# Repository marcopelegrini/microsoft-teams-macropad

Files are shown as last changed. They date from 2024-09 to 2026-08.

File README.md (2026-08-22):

# Microsoft Teams Macropad

Microsoft Teams Macropad is a physical device, programmed specifically for Microsoft Teams with dedicated keys for triggering functionalities such as "mute" or "raise hand", as well as reactions to meetings and chats!

Documentation: https://pelegrini.ca/hardware/2024/11/10/marcopad/

These are all the asseets I've used to create the macropad. 

Feel free to fork, modify and suggest changes, as long as you keep everything free and never commercialize it.

> This required modifications to Microsoft Teams which are not publicly available yet. So be aware that to take the full advantage of this project you might need to wait until those changes makes into the public available version.<br/><br/>
> Functions that work out-of-the-box are Mute/Unmute and Haise/Lower hands<br/><br/>
> You can also program any of [Microsoft Teams Shortcuts](https://support.microsoft.com/en-us/office/keyboard-shortcuts-for-microsoft-teams-2e8e2a70-e8d8-4a19-949b-4c36dd5292d2) to the other keys instead of the reactions/Copilot ones

Each older in this repo has it's own documentation about each project component

Cheers

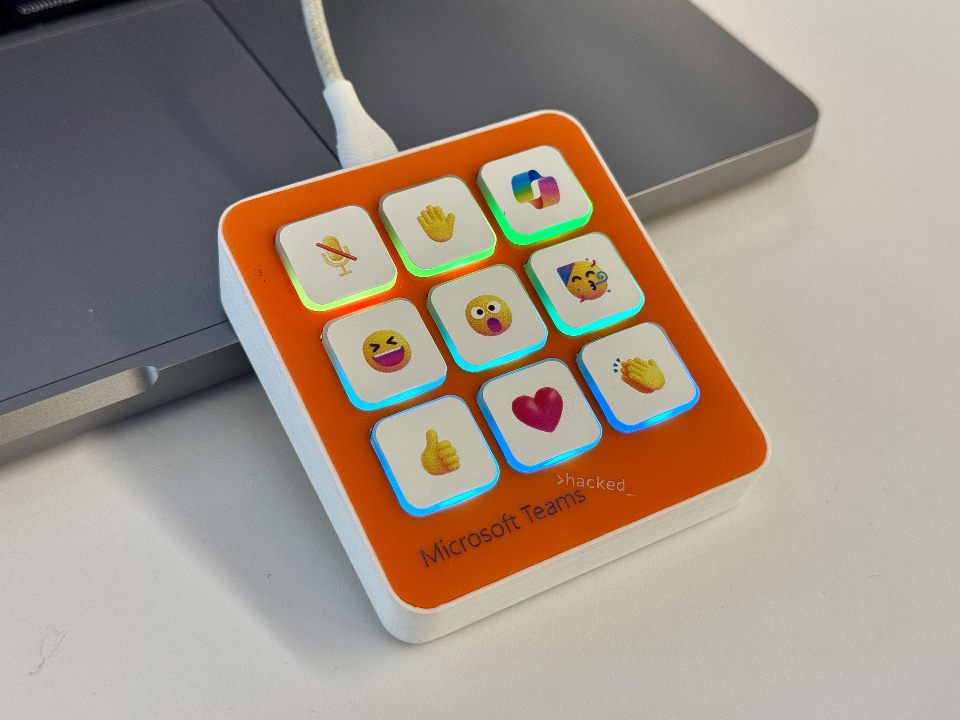
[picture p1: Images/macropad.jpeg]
Microsoft Teams Macropad


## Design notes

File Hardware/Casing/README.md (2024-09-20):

# Casing

```
3D Printed, using PLA fillament.
Weighted plates added for "premium feel"
```

- Printer: [UltiMaker S5](https://ultimaker.com/3d-printers/s-series/ultimaker-s5/)
- Software: [UltiMaker Cura](https://ultimaker.com/software/ultimaker-cura/)

Use the STL file in this folder for printing

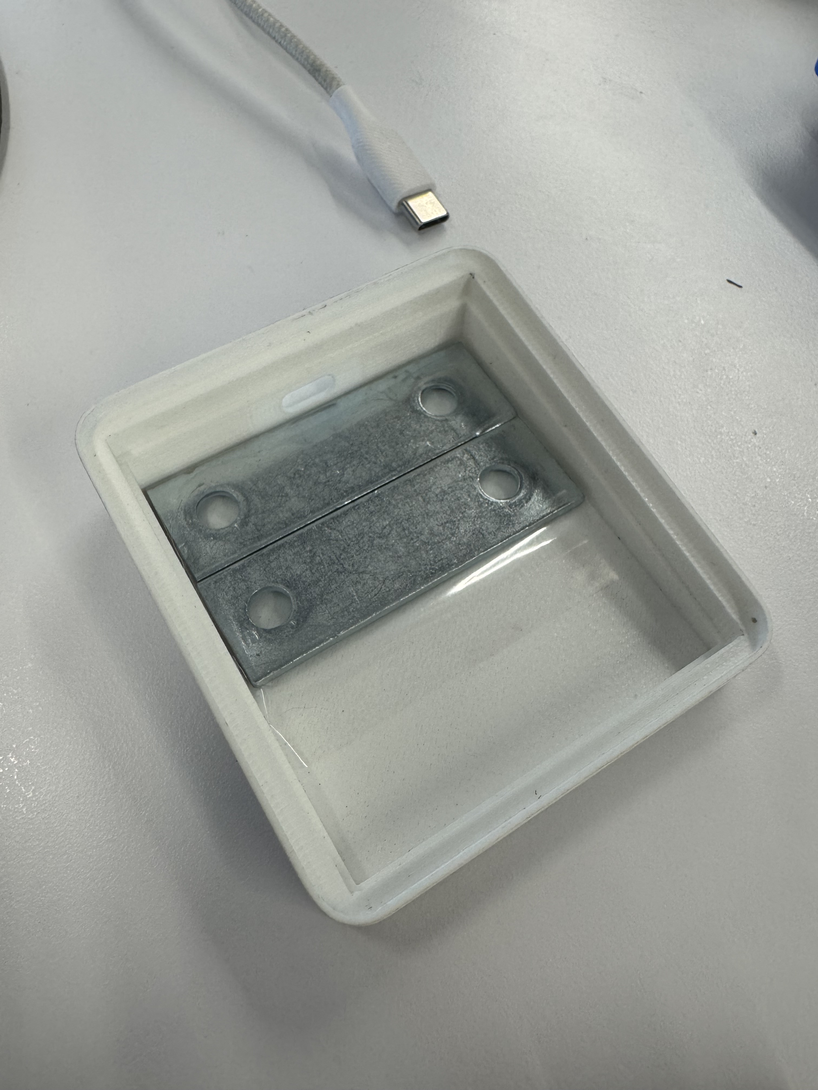
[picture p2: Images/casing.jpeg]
Casing


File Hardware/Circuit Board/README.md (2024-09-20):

# Circuit Board

```
Single sided-board milled using a desktop CNC milling machine. The one I've used is discontinued, so I've liked the latest model

PCB design done using KiCad
```

- CNC (similar): [Bantam tools](https://store.bantamtools.com/products/bantam-tools-desktop-cnc-milling-machine)
- Software: [Kicad](https://www.kicad.org/)

KiCad files available in the KiCad folder

I opted for the cheapest setup giving this was going to be my first try.<br/>
I've used an RP2040 USB-C, but a more sophisticated board can be used, for bluetooth connectivity for instance.

The buttons are simple tactile switches I had laying around glued to the "keys" cut from the Façade (front plate).<br/>
You can definitelly do better with proper keyboard switches ([like this guy](https://kbd.news/Mask-keyboard-1819.html)), but I was going with what I had in hand.<br/>

Because I wasn't expecting to use more than one key at the time, I've used a simple matrix keyboard layout **without diodes**, but consider adding diodes in case you're creating combination of keys.<br/>
For instance, you can have multiple layers for even more functions and adding a combination of keys to switch between layers.

For RGB lights, I've used a few neopixels I had laying around. You can do better by using keyboard switches with embedded lights on them.

## Parts
- [Raspberry Pi Pico](https://www.raspberrypi.com/products/raspberry-pi-pico/)
- [Tactile switch](https://www.digikey.ca/en/products/detail/same-sky/TS02-66-60-BK-160-LCR-D/15634268)
- [LED Strip](https://www.adafruit.com/product/1138)

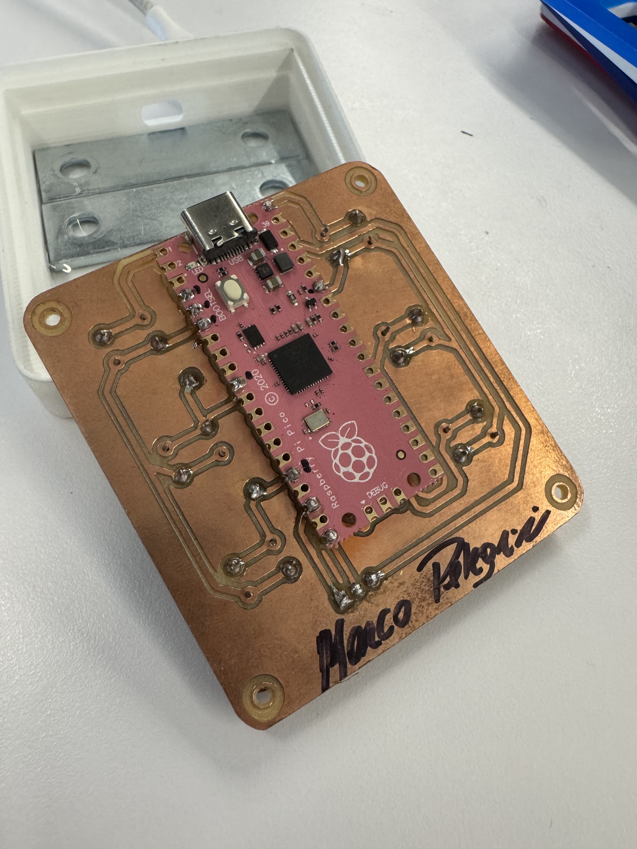
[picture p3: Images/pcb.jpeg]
PCB

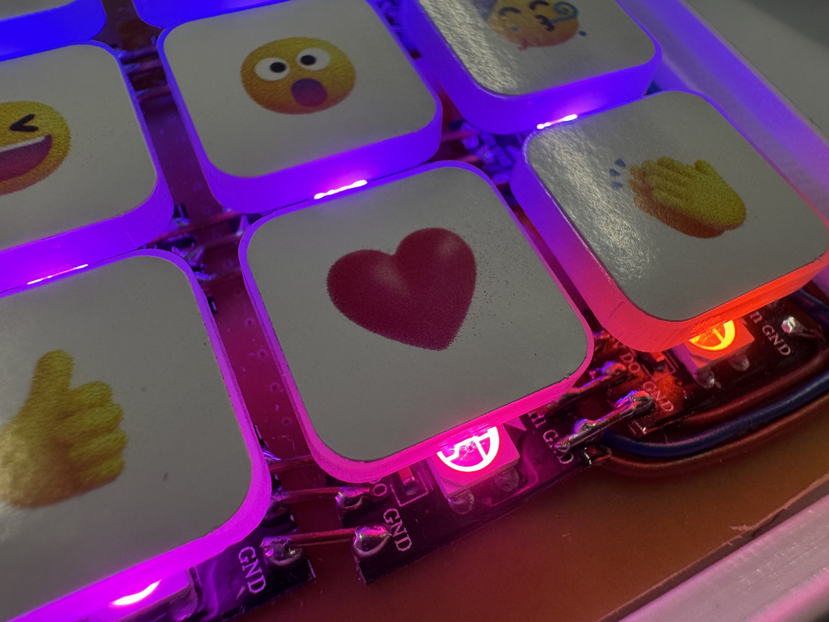
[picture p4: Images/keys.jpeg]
Keys


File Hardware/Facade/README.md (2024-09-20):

# Façade (front plate)

```
Cut and etched using a laser cutter
```

- Laser cutter: [UNIVERSAL 4.60](https://www.ulsinc.com)

Use vector files in this folder for cutting

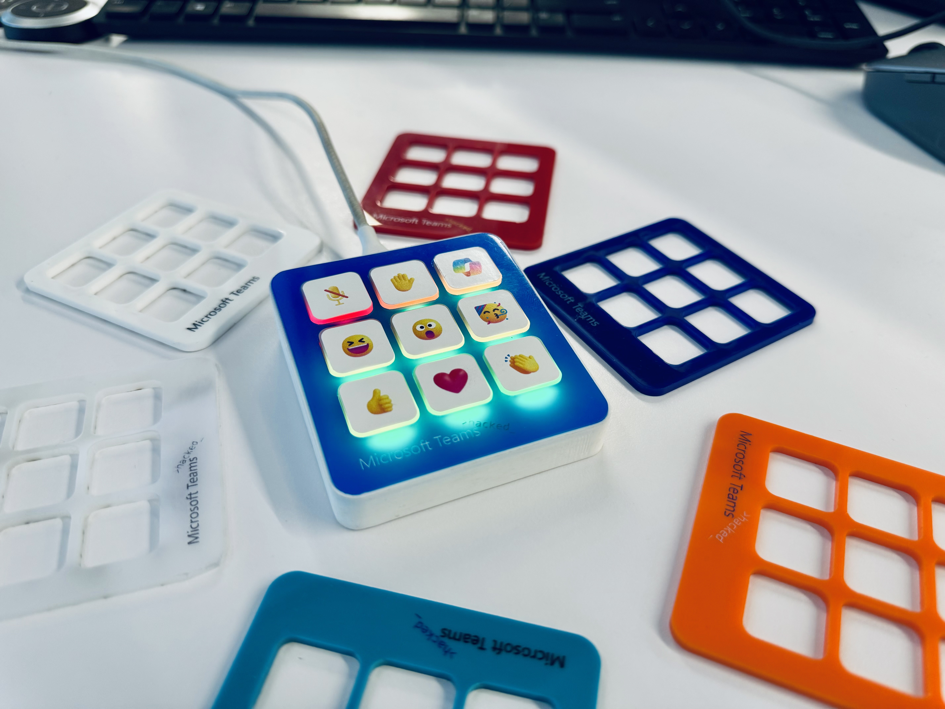
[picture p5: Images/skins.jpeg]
Casing


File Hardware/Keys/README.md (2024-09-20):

# Stickers

```
Printed and cut using a large format printer/plotter
```

- Printer/plotter: [Roland BN-20 ](https://www.rolanddga.com/products/printers/versastudio-bn-20-t-shirt-printing-press)

Use the files in this folder for images/cutting

Casing

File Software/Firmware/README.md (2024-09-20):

# Firmware

```
The macropad is actually a custom keyboard, using KMK firmware
```

- Firmware: [KMK](https://github.com/KMKfw/kmk_firmware)
- KMK GUI: [POG](https://github.com/JanLunge/pog)

I've oped for KMK because it's much simpler to run the experiments, you can edit the layout on the fly and test different key combinations, which helped me during the development

Now that I'm done making modifications, I'll probably switch to a firmware that doesn't use CircuitPython for more stability. CircuitPython mounts a local drive (which is why it's easy to update), but that's prone to corruption and is not as fast as other firmwares like QMK.

There's a backup of my firmware in this folder... but setting it up from scratch is very easy, just follow POG's tutorials.

POG

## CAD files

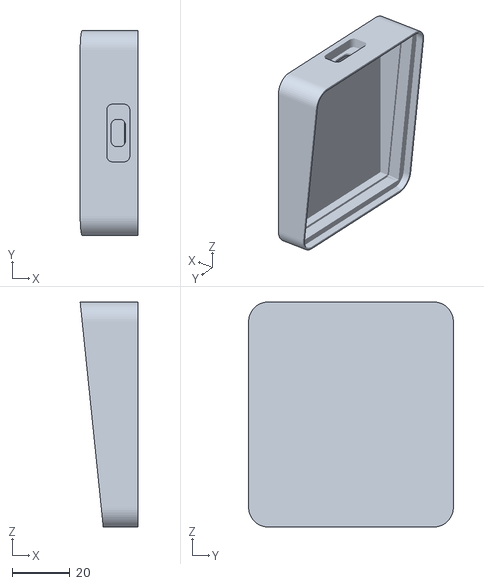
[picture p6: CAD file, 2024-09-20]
Hardware/Casing/Teams Keyboard Casing.stl
20.0 x 71.0 x 78.0

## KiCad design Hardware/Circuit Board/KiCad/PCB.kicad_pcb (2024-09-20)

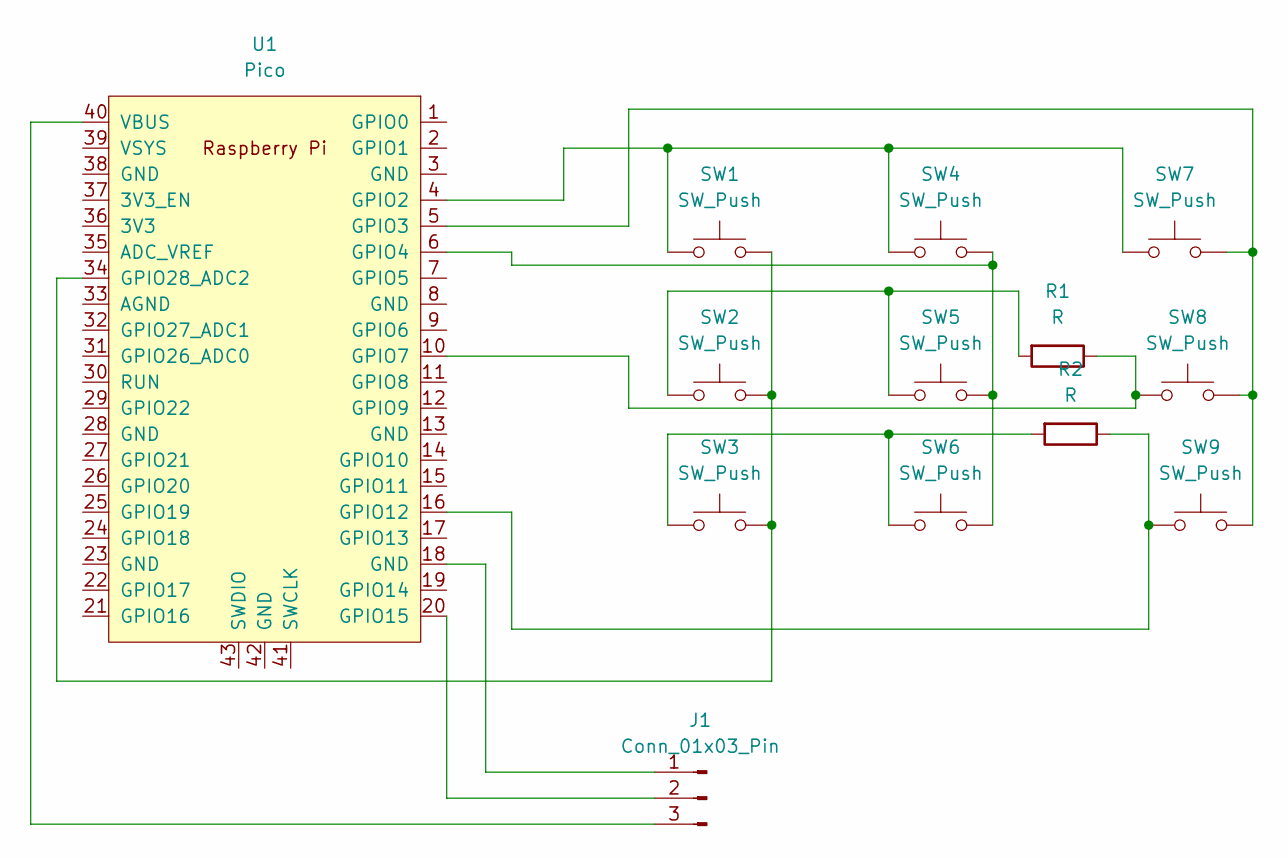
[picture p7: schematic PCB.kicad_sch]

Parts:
J1: Conn_01x03_Pin; PinSocket_1x03_P2.54mm_Vertical
R1, R2: R; R_Axial_DIN0207_L6.3mm_D2.5mm_P10.16mm_Horizontal
SW1, SW2, SW3, SW4, SW5, SW6, SW7, SW8, SW9: SW_Push; SW_PUSH_6mm
U1: Pico; RPi_Pico_SMD_TH

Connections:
unnamed: J1.1, U1.18 (GND)
unnamed: J1.2, U1.20 (GPIO15)
unnamed: J1.3, U1.40 (VBUS)
unnamed: R1.2, SW2.1, SW5.1
unnamed: R2.2, SW3.1, SW6.1
unnamed: SW1.1, SW4.1, SW7.1, U1.4 (GPIO2)
unnamed: SW7.2, SW8.2, SW9.2, U1.5 (GPIO3)
unnamed: SW4.2, SW5.2, SW6.2, U1.6 (GPIO4)
unnamed: R1.1, SW8.1, U1.10 (GPIO7)
unnamed: R2.1, SW9.1, U1.16 (GPIO12)
unnamed: SW1.2, SW2.2, SW3.2, U1.34 (GPIO28_ADC2)

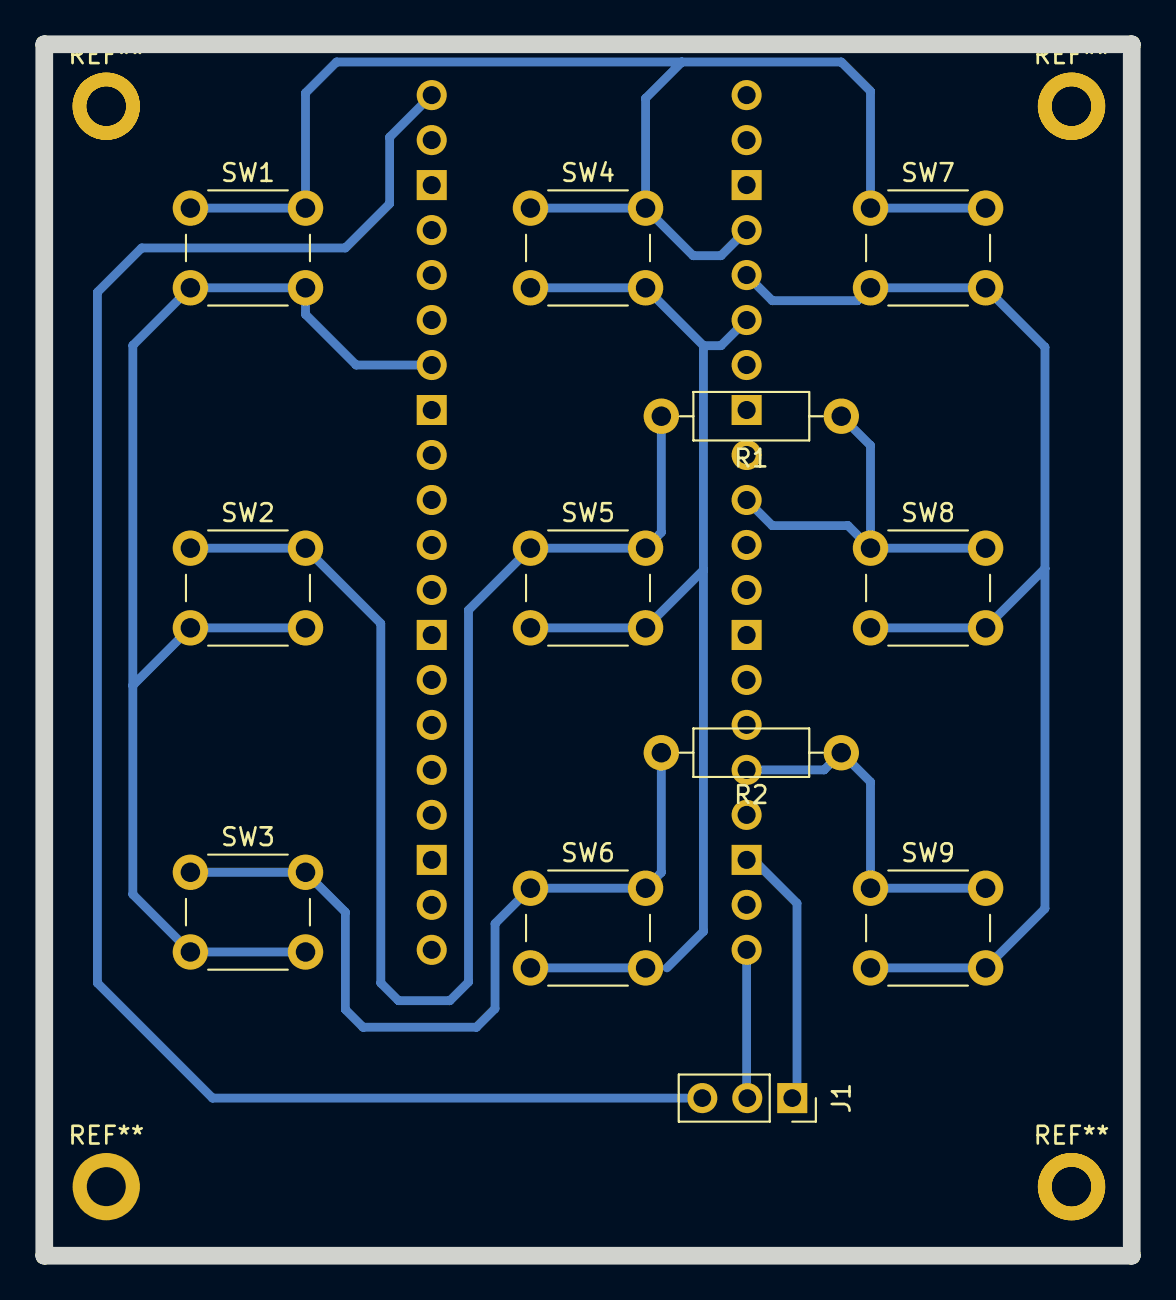
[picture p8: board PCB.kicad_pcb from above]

Board: 2 copper layers, 61.4 x 68.4 mm, 13 parts (1 on the bottom side), 11 nets.
